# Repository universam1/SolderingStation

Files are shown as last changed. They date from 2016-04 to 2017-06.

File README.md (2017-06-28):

# SolderingStation

Schematics and Code for a DIY Weller RT soldering station.

Find original idea at https://debugginglab.wordpress.com/2014/10/30/soldering-station/

## Additions

- Calculating Power usage by measuring the input voltage
- Limit Power dynamically, displaying it
- allowing different voltage PSUs
- more UI changes
- more convenient Poti mappings
- introducing serial command to configure (more to do)

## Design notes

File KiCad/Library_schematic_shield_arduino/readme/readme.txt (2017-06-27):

# About:
library shield_arduino 

(for arduino board version make from 2009 and after)

#Contains: 
the KiCAD schematic for some "ARDUINO" board:

ARDUINO_as_UNO		schématic for build a shield or clone an "arduino as UNO " based on revision 3
ARDUINO_FIO		schématic for build a shield or clone an "arduino FIO" based on version 22
ARDUINO_MEGA		schématic for build a shield or clone an "arduino MEGA 2560 " based on revision 3 
ARDUINO_MICRO		schématic for build a shield or clone an "arduino MICRO " based on revision 3
ARDUINO_MINI_PRO	schématic for build a shield or clone an "arduino PRO MINI " based on version 10
ARDUINO_MINI		schématic for build a shield or clone an "arduino MINI " based on version 5
ARDUINO_NANO		schématic for build a shield or clone an "arduino NANO" based on version 2

/!\Attention/!\ 

GND/1, GND/2 ou TX/1, TX/2 ou 5V/1, 5V/2 ect... as the same in your board but it was separate in these modules.
Just for more free during your construction.

Schematics not contains the ISP connector.

Pin are placing like your official boards

Just verifi if pins are present, depending your board version and adjust in consequence.

Be careful the library may contain errors.

(partie en français)

/!\Attention/!\ 

Les pins marquées GND/1, GND/2 ou TX/1, TX/2 ou 5V/1, 5V/2 ect... sont connectées 
entre elles sur les cartes officielles. 
Sur les schémats je l'ai est dissocié pour vous laissez plus de 
liberté dans la fabriction de vos shields ou vos clones...

Les schémas ne contiennent pas le connecteur ISP.

L'arrangement des connections sur le schémat et suivant le placement des pins sur
les cartes officielles 

Vérifier la version de votre carte et la présence des pins. 
Ajuster en conséquence.

La librairie peut contenir des défauts alors vérifier deux fois.

Author: Jonathan Iapicco / France / 27 nov. 2014
License: GNU-GPL

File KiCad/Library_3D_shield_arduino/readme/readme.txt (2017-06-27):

# About
library 3D shield_arduino 

(for arduino board version make from 2009 and after)

#Contains: 
the KiCAD 3D views, formats: ".Wrl" and ".wings" for some
"ARDUINO" board:

arduino_MICRO_header.wings
arduino_MICRO_header.wrl
arduino_MICRO_header_down.wings
arduino_MICRO_header_down.wrl
arduino_MICRO_header_long.wings
arduino_MICRO_header_long.wrl
arduino_MICRO_pin_strip.wings
arduino_MICRO_pin_strip.wrl
arduino_MICRO_pin_strip_double.wings
arduino_MICRO_pin_strip_double.wrl
arduino_MICRO_pin_strip_down.wings
arduino_MICRO_pin_strip_down.wrl

arduino_MINI_header.wings
arduino_MINI_header.wrl
arduino_MINI_header_down.wings
arduino_MINI_header_down.wrl
arduino_MINI_header_long.wings
arduino_MINI_header_long.wrl
arduino_MINI_pin_strip.wings
arduino_MINI_pin_strip.wrl
arduino_MINI_pin_strip_double.wings
arduino_MINI_pin_strip_double.wrl
arduino_MINI_pin_strip_down.wings
arduino_MINI_pin_strip_down.wrl

arduino_FIO_header.wings
arduino_FIO_header.wrl
arduino_FIO_header_down.wings
arduino_FIO_header_down.wrl
arduino_FIO_header_long.wings
arduino_FIO_header_long.wrl
arduino_FIO_pin_strip.wings
arduino_FIO_pin_strip.wrl
arduino_FIO_pin_strip_double.wings
arduino_FIO_pin_strip_double.wrl
arduino_FIO_pin_strip_down.wings
arduino_FIO_pin_strip_down.wrl

arduino_MEGA_header.wings
arduino_MEGA_header.wrl
arduino_MEGA_header_down.wings
arduino_MEGA_header_down.wrl
arduino_MEGA_header_down+.wings
arduino_MEGA_header_down+.wrl
arduino_MEGA_header_long.wings
arduino_MEGA_header_long.wrl
arduino_MEGA_header_long+.wings
arduino_MEGA_header_long+.wrl
arduino_MEGA_pin_strip.wings
arduino_MEGA_pin_strip.wrl
arduino_MEGA_pin_strip+.wings
arduino_MEGA_pin_strip+.wrl
arduino_MEGA_pin_strip_double.wings
arduino_MEGA_pin_strip_double.wrl
arduino_MEGA_pin_strip_down.wings
arduino_MEGA_pin_strip_down.wrl

arduino_MINI_PRO_header.wings
arduino_MINI_PRO_header.wrl
arduino_MINI_PRO_header_down.wings
arduino_MINI_PRO_header_down.wrl
arduino_MINI_PRO_header_long.wings
arduino_MINI_PRO_header_long.wrl
arduino_MINI_PRO_pin_strip.wings
arduino_MINI_PRO_pin_strip.wrl
arduino_MINI_PRO_pin_strip_double.wings
arduino_MINI_PRO_pin_strip_double.wrl
arduino_MINI_PRO_pin_strip_down.wings
arduino_MINI_PRO_pin_strip_down.wrl

arduino_NANO_header.wings
arduino_NANO_header.wrl
arduino_NANO_header_down.wings
arduino_NANO_header_down.wrl
arduino_NANO_header_long.wings
arduino_NANO_header_long.wrl
arduino_NANO_pin_strip.wings
arduino_NANO_pin_strip.wrl
arduino_NANO_pin_strip_double.wings
arduino_NANO_pin_strip_double.wrl
arduino_NANO_pin_strip_down.wings
arduino_NANO_pin_strip_down.wrl

arduino_UNO_header.wings
arduino_UNO_header.wrl
arduino_UNO_header_down.wings
arduino_UNO_header_down.wrl
arduino_UNO_header_long.wings
arduino_UNO_header_long.wrl
arduino_UNO_pin_strip.wings
arduino_UNO_pin_strip.wrl
arduino_UNO_pin_strip_double.wings
arduino_UNO_pin_strip_double.wrl
arduino_UNO_pin_strip_down.wings
arduino_UNO_pin_strip_down.wrl

All view are made in "inch" with any export offset.

The directory "demo_library_wings" contains all modules 
3D for demonstration, you can use it for select your 3D view.

File "extra.wings" contain all pins i used and little more in format ".wings".
You can use for create your personnal view.
 
For open you need the software -> "wings 3D" 
You can download at : http://www.wings3d.com/

Be careful the library may contain errors

(partie en français)

Toutes les vues sont construites en "pouce" sans offset à l'exportation.

Le répertoire "demo_library_wings" contient tous l'ensemble des modules 3D.
Vous pouvez vous en servir pour visualiser et choisir votre vue 3D.

Le fichier "extra.wings" contient les éléments 3D au format ".wings" que j'ai utilisé pour
faire les modules. Vous pouvez ainsi adapter vos vues selon vos besoins.

Pour utiliser les fichier ".wings" il vous faut le logiciel "wings 3D"
que vous pouvez trouver ici: http://www.wings3d.com/

Attention les vues peuvent contenir des défauts alors vérifier deux fois.

Author: Jonathan Iapicco / France / 27 nov. 2014
License: GNU-GPL

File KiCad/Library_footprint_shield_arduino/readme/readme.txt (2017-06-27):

# About:
library footprint SHIELD_ARDUINO 

(for arduino board version make from 2009 and after)

#Contains: 
the KiCAD footprint for some "ARDUINO" board:

ARDUINO_FIO_V22				Footprint contain only pin connectors. 
ARDUINO_FIO_V22_CONTOUR			Footprint contain pin connectors, board contour and position (VCC, USB, ISP, RESET button).
ARDUINO_FIO_V22_ELL			Footprint with large pads.
ARDUINO_FIO_V22_CONTOUR-ELL		Footprint with large pads.
ARDUINO_MEGA_2560_R3			Footprint contain only pin connectors and holes.
ARDUINO_MEGA_2560_R3_CONTOUR 		Footprint contain pin connectors, board contour and position (VCC, USB, ISP, RESET button).
ARDUINO_MEGA_2560_R3_ELL		Footprint with large pads.
ARDUINO_MEGA_2560_R3_CONTOUR_ELL	Footprint with large pads.
ARDUINO_MICRO_R3			Footprint contain only pin connectors and holes.
ARDUINO_MICRO_R3_CONTOUR		Footprint contain pin connectors, board contour and position (USB, ISP, RESET button).
ARDUINO_MICRO_R3_ELL			Footprint with large pads.
ARDUINO_MICRO_R3_CONTOUR_ELL		Footprint with large pads.
ARDUINO_MINI_PRO_V10			Footprint contain only pin connectors.
ARDUINO_MINI_PRO_V10_CONTOUR		Footprint contain pin connectors, board contour and position (RESET button).
ARDUINO_MINI_PRO_V10_ELL		Footprint with large pads.
ARDUINO_MINI_PRO_V10_CONTOUR_ELL	Footprint with large pads.
ARDUINO_MINI_V5				Footprint contain only pin connectors.
ARDUINO_MINI_V5_CONTOUR			Footprint contain pin connectors, board contour and position (RESET button).	
ARDUINO_MINI_V5_ELL			Footprint with large pads.	
ARDUINO_MINI_V5_CONTOUR_ELL		Footprint with large pads.
ARDUINO_NANO_2				Footprint contain only pin connectors and holes.
ARDUINO_NANO_2_CONTOUR			Footprint contain pin connectors, board contour and position (USB, ISP, RESET button).
ARDUINO_NANO_2_ELL			Footprint with large pads.	
ARDUINO_NANO_2_CONTOUR_ELL		Footprint with large pads.
ARDUINO_as_UNO_R3			Footprint contain only pin connectors and holes.
ARDUINO_as_UNO_R3_CONTOUR		Footprint contain pin connectors, board contour and position (VCC, USB, ISP, RESET button).
ARDUINO_as_UNO_R3_ELL			Footprint with large pads.
ARDUINO_as_UNO_R3_CONTOUR_ELL		Footprint with large pads.

/!\IMPORTANT: use directory "SHIELD_ARDUINO.pretty" if your have a new KICAD version (version >= BZR 5000).
Else if your have an old KICAD version use "SHIELD_ARDUINO.mod" /!\ 

GND/1, GND/2 ou TX/1, TX/2 ou 5V/1, 5V/2 ect... as the same in your board but it was separate in these modules.
Just for more free during your construction.

The postion of connectors (VCC, USB, ISP and reset) and holes are there for information purposes.
Adujst your footprint what do you want. 

Be careful the library may contain errors.

(Partie en français)

/!\Attention/!\ 

Les pins marquées GND/1, GND/2 ou TX/1, TX/2 ou 5V/1, 5V/2 ect... sont connectées 
entre elles sur les cartes officielles mais séparées sur ces modules. Cela vous laisse plus de liberté. 

Utiliser le répertoire "SHIELD_ARDUINO.pretty" si votre version de kicad est supérieur ou égale à la
"BZR 5110".
Sinon utiliser "SHIELD_ARDUINO.mod".

Les empreintes type "arduino_board_contour" contiennent le contour des cartes.
Mais aussi l'emplacement des trous, du connecteur "ISP", du bouton "RESET", des connecteurs 
"USB" et de l'alimentation si il y en a. 
Ils sont tracés avec des traits d'une épaisseur de "0.01mm" alors que les contours sont en "0.15mm".

Le but étant de vous donnez un maximum d'informations et d'ajuster selon vos besoins. 

Vérifier la version de votre carte et la présence des pins. 
Ajuster en conséquence.

La librairie peut contenir des erreurs alors vérifier deux fois.

Author:	 Jonathan Iapicco / France / 27 nov. 2014
License: GNU-GPL

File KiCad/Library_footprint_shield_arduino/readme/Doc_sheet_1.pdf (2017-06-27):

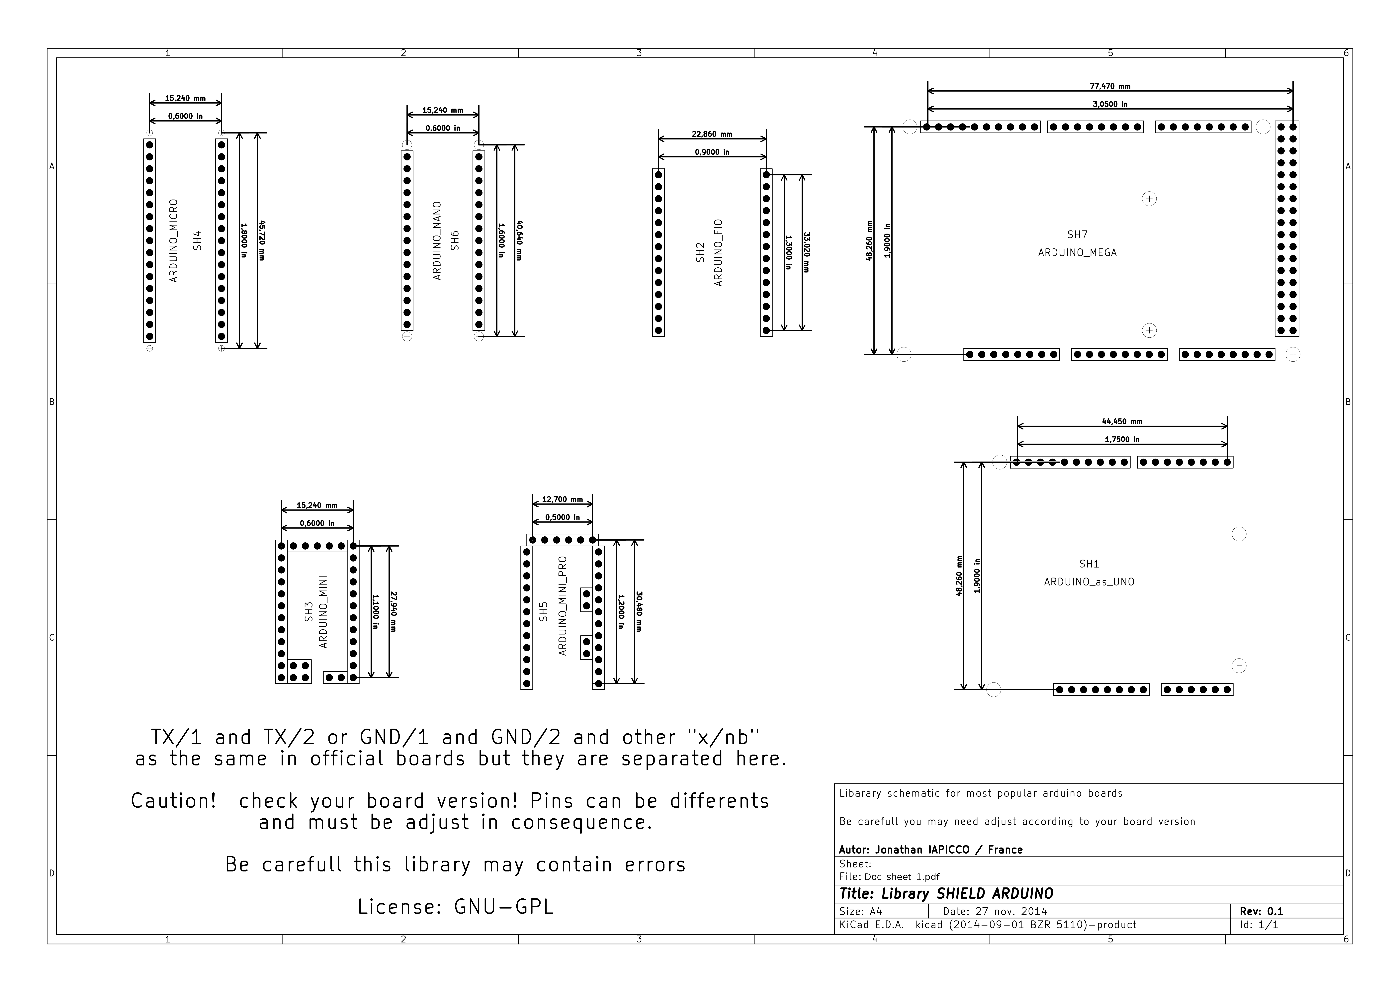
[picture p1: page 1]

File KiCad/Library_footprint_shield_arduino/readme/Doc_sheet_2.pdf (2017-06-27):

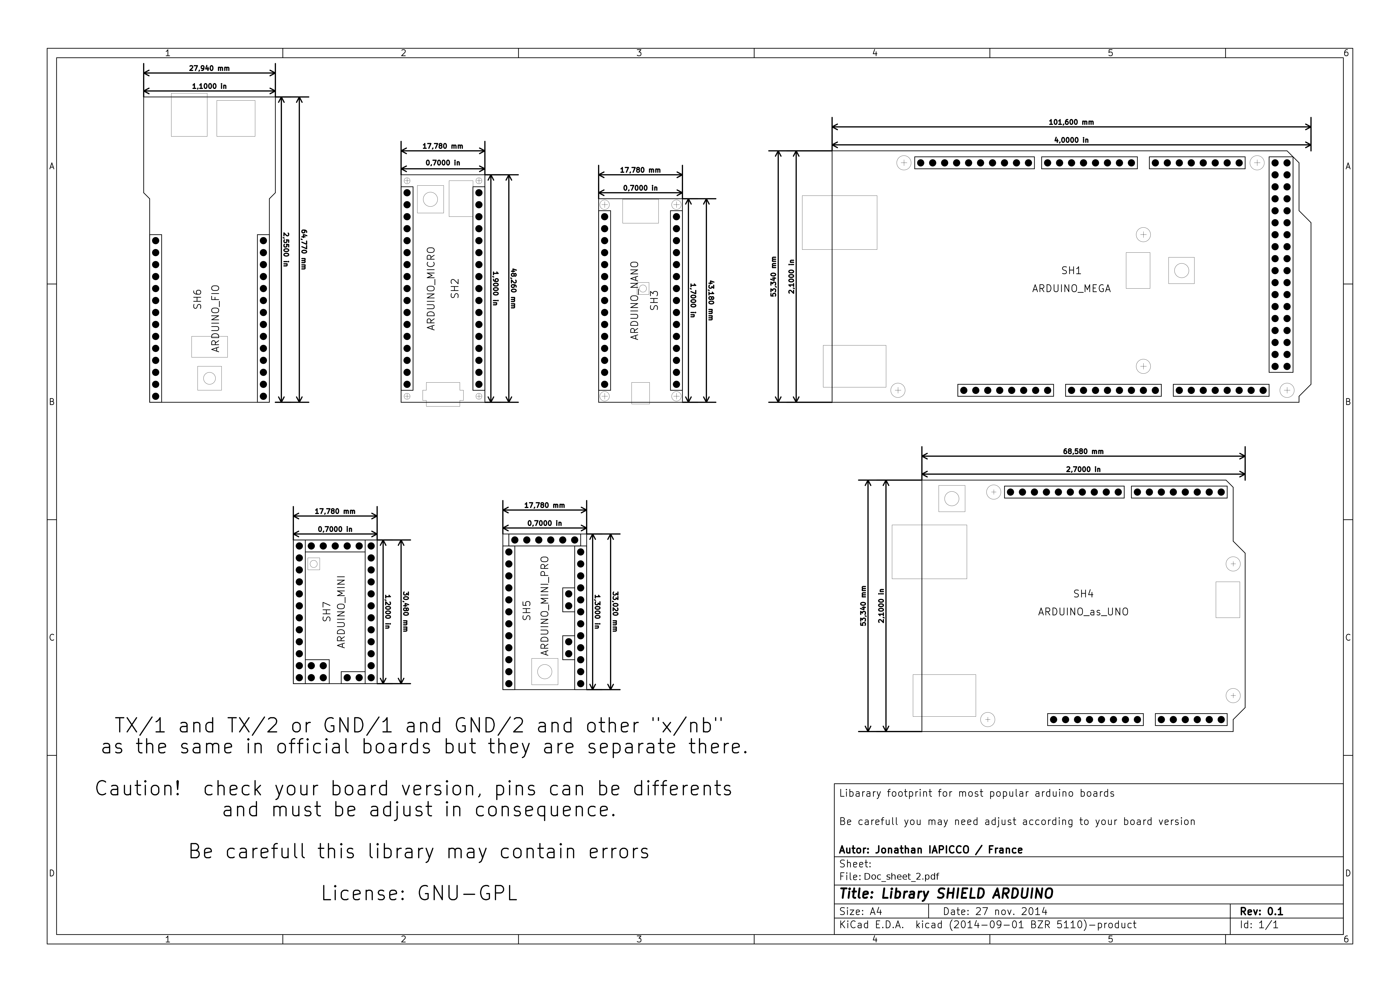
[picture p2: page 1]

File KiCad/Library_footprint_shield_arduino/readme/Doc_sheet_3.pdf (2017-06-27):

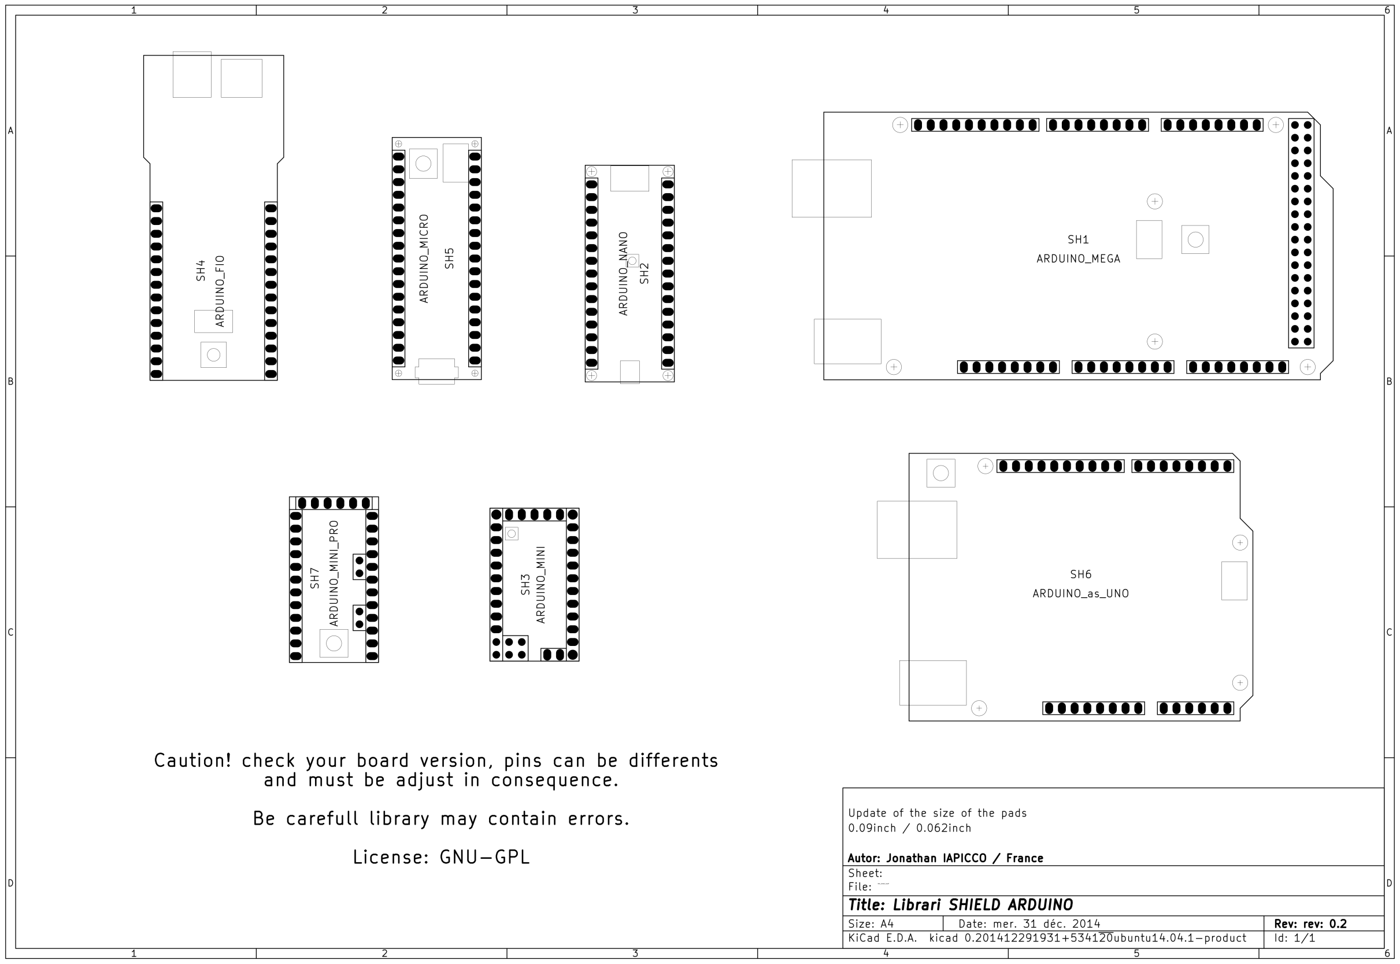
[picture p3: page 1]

Doc_sheet_3.pdf

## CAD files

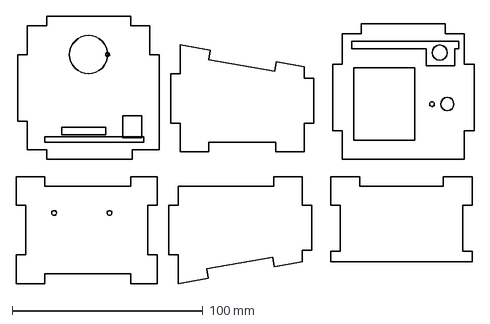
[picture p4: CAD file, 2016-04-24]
2D5/solderstation_gehäuse.dxf
240.0 x 140.1 mm

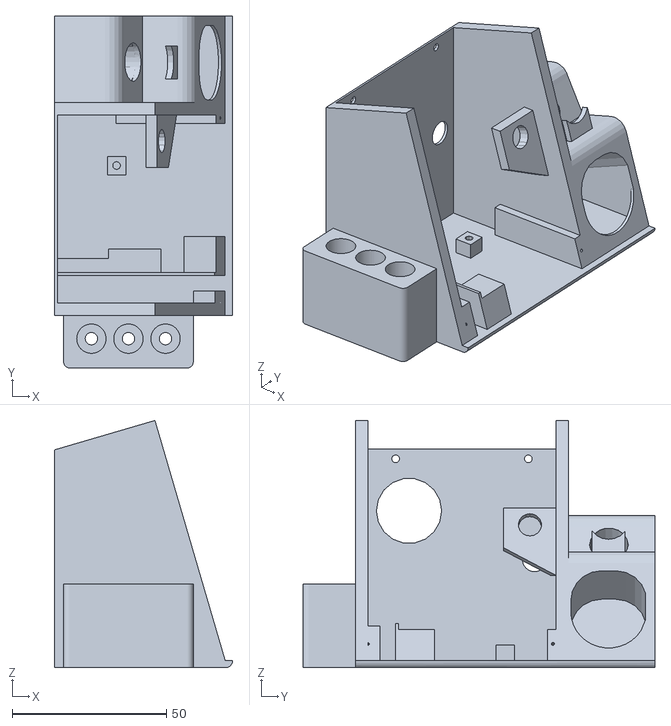
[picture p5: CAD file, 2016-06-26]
3D/lotstationv2.2.stl
57.7 x 114.0 x 80.0

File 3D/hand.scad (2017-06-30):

use<thread.scad>;

$fn = 50;

$hl = 100;
$h1 = 10.6;
$h2 = 28.6;
$h3 = 14;
$h4 = 12;
$h5 = $hl - ($h1 + $h2 + $h3 + $h4);

module huelle()
{
    difference()
    {
        translate([ 0, 0, 41 ])
            scale([ 0.18, 0.18, 1 ])
            sphere(r = 62);
        translate([ 0, 0, -50 ]) cube(size = [ 100, 100, 100 ], center = true);
        translate([ 0, 0, $hl + 50 ]) cube(size = [ 100, 100, 100 ], center = true);
    }
}

module handle_bottom()
{
    difference()
    {
        union()
        {
            huelle();

            // cylinder(h=$h1+$h2+$h3, r=13/2);
        }
        cylinder(h = $h1, r = 9.8 / 2);
        translate([ 0, 0, $h1 ]) cylinder(h = $h2, r = 10.6 / 2);
        translate([ 0, 0, $h1 + $h2 ]) metric_thread(diameter = 15, pitch = 1.5, length = $h3, internal = true);
        translate([ 0, 0, $h1 + $h2 + $h3 + 50 ]) cube(size = [ 100, 100, 100 ], center = true);
    }
}

module handle_top()
{
    difference()
    {
    union()
    {
        difference()
        {
            huelle();
            translate([ 0, 0, $h1 + $h2 + $h3 - 50 ]) cube(size = [ 100, 100, 100 ], center = true);
        }
        difference()
        {
            translate([ 0, 0, $h1 + $h2 + 2 ]) metric_thread(diameter = 14.4, pitch = 1.5, length = $h3 - 2);
            translate([ 0, 0, $h1 + $h2 ]) cylinder(h = $h3, r = 6.1 / 2);
        }
    }
        // union()
        // {
            // translate([ 0, 0, $h1 + $h2 + $h3 ]) cylinder(h = $h4, r = 12.8 / 2);
            // translate([ 0, 0, $h1 + $h2 + $h3 + $h4 ]) cylinder(h = $h5, r = 12.8 / 2, r2 = 8 / 2);
        
        translate([ 0, 0, $h1 + $h2 + $h3 ]) cylinder(h = $h4 + $h5, r = 4.8 / 2);
    }
}

difference()
{
    union()
    {
        // handle_top();
        handle_bottom();
    }
    // translate([ 0, -15, 0 ]) cube([ 20, 30, 200 ]);
}

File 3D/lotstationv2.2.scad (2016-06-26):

$fn=50;

module object() {
    translate([28.5,32.20,0.25]) {
        import("/Users/waldemar/Projekte/SolderingStation/3D/lotstationv2.1.stl");
    }
    translate([0,52, 13]) color("red") cube([1,12,14]);
}

module holder() {
    union() {
        translate([12,-7.5,14.5]) cylinder(h= 13, r=9.5/2);
        translate([12,-7.5,0]) cylinder(h= 30, r=4/2);
    }
}

difference() {
    object();
    translate([-5,58, 35]) rotate([0,90,0]) cylinder(h= 30, r=7.9/2);
}

difference() {
    translate([5,-15,0]) minkowski() {
        cube([39,16.5,26]);
        cylinder(r=2,h=1);
    }
     
    holder();
    translate([12.5, 0,0]) holder();
    translate([25, 0,0]) holder();
}

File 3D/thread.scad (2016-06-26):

/*
 * ISO-standard metric threads, following this specification:
 *          http://en.wikipedia.org/wiki/ISO_metric_screw_thread
 *
 * Dan Kirshner - dan_kirshner@yahoo.com
 *
 * You are welcome to make free use of this software.  Retention of my
 * authorship credit would be appreciated.
 *
 * Version 1.8.  2016-01-08  Option: (non-standard) angle.
 * Version 1.7.  2015-11-28  Larger x-increment - for small-diameters.
 * Version 1.6.  2015-09-01  Options: square threads, rectangular threads.
 * Version 1.5.  2015-06-12  Options: thread_size, groove.
 * Version 1.4.  2014-10-17  Use "faces" instead of "triangles" for polyhedron
 * Version 1.3.  2013-12-01  Correct loop over turns -- don't have early cut-off
 * Version 1.2.  2012-09-09  Use discrete polyhedra rather than linear_extrude ()
 * Version 1.1.  2012-09-07  Corrected to right-hand threads!
 */

// Examples.
//
// Standard M8 x 1.
// metric_thread (diameter=8, pitch=1, length=4);

// Square thread.
// metric_thread (diameter=8, pitch=1, length=4, square=true);

// Non-standard: long pitch, same thread size.
//metric_thread (diameter=8, pitch=4, length=4, thread_size=1, groove=true);

// Non-standard: 20 mm diameter, long pitch, square "trough" width 3 mm,
// depth 1 mm.
//metric_thread (diameter=20, pitch=8, length=16, square=true, thread_size=6, 
//               groove=true, rectangle=0.333);

// English: 1/4 x 20.
//english_thread (diameter=1/4, threads_per_inch=20, length=1);

// Thread for mounting on Rohloff hub.
//difference () {
//   cylinder (r=20, h=10, $fn=100);
//
//   metric_thread (diameter=34, pitch=1, length=10, internal=true, n_starts=6);
//}


// ----------------------------------------------------------------------------
function segments (diameter) = min (50, ceil (diameter*6));


// ----------------------------------------------------------------------------
// internal -    true = clearances for internal thread (e.g., a nut).
//               false = clearances for external thread (e.g., a bolt).
//               (Internal threads should be "cut out" from a solid using
//               difference ()).
// n_starts -    Number of thread starts (e.g., DNA, a "double helix," has
//               n_starts=2).  See wikipedia Screw_thread.
// thread_size - (non-standard) size of a single thread "V" - independent of
//               pitch.  Default: same as pitch.
// groove      - (non-standard) subtract inverted "V" from cylinder (rather than
//               add protruding "V" to cylinder).
// square      - Square threads (per 
//               https://en.wikipedia.org/wiki/Square_thread_form).
// rectangle   - (non-standard) "Rectangular" thread - ratio depth/width
//               Default: 1 (square).
// angle       - (non-standard) angle (deg) of thread side from perpendicular to
//               axis (default = standard = 30 degrees).
module metric_thread (diameter=8, pitch=1, length=1, internal=false, n_starts=1,
                      thread_size=-1, groove=false, square=false, rectangle=0,
                      angle=30)
{
   // thread_size: size of thread "V" different than travel per turn (pitch).
   // Default: same as pitch.
   local_thread_size = thread_size == -1 ? pitch : thread_size;
   local_rectangle = rectangle ? rectangle : 1;

   n_segments = segments (diameter);
   h = (square || rectangle) ? local_thread_size*local_rectangle/2 : local_thread_size * cos (angle);

   h_fac1 = (square || rectangle) ? 0.90 : 0.625;

   // External thread includes additional relief.
   h_fac2 = (square || rectangle) ? 0.95 : 5.3/8;

   if (! groove) {
      metric_thread_turns (diameter, pitch, length, internal, n_starts, 
                           local_thread_size, groove, square, rectangle, angle);
   }

   difference () {

      // Solid center, including Dmin truncation.
      if (groove) {
         cylinder (r=diameter/2, h=length, $fn=n_segments);
      } else if (internal) {
         cylinder (r=diameter/2 - h*h_fac1, h=length, $fn=n_segments);
      } else {

         // External thread.
         cylinder (r=diameter/2 - h*h_fac2, h=length, $fn=n_segments);
      }

      if (groove) {
         metric_thread_turns (diameter, pitch, length, internal, n_starts, 
                              local_thread_size, groove, square, rectangle,
                              angle);
      }
   }
}


// ----------------------------------------------------------------------------
// Input units in inches.
// Note: units of measure in drawing are mm!
module english_thread (diameter=0.25, threads_per_inch=20, length=1,
                      internal=false, n_starts=1, thread_size=-1, groove=false,
                      square=false, rectangle=0)
{
   // Convert to mm.
   mm_diameter = diameter*25.4;
   mm_pitch = (1.0/threads_per_inch)*25.4;
   mm_length = length*25.4;

   echo (str ("mm_diameter: ", mm_diameter));
   echo (str ("mm_pitch: ", mm_pitch));
   echo (str ("mm_length: ", mm_length));
   metric_thread (mm_diameter, mm_pitch, mm_length, internal, n_starts, 
                  thread_size, groove, square, rectangle);
}

// ----------------------------------------------------------------------------
module metric_thread_turns (diameter, pitch, length, internal, n_starts, 
                            thread_size, groove, square, rectangle, angle)
{
   // Number of turns needed.
   n_turns = floor (length/pitch);

   intersection () {

      // Start one below z = 0.  Gives an extra turn at each end.
      for (i=[-1*n_starts : n_turns+1]) {
         translate ([0, 0, i*pitch]) {
            metric_thread_turn (diameter, pitch, internal, n_starts, 
                                thread_size, groove, square, rectangle, angle);
         }
      }

      // Cut to length.
      translate ([0, 0, length/2]) {
         cube ([diameter*3, diameter*3, length], center=true);
      }
   }
}


// ----------------------------------------------------------------------------
module metric_thread_turn (diameter, pitch, internal, n_starts, thread_size,
                           groove, square, rectangle, angle)
{
   n_segments = segments (diameter);
   fraction_circle = 1.0/n_segments;
   for (i=[0 : n_segments-1]) {
      rotate ([0, 0, i*360*fraction_circle]) {
         translate ([0, 0, i*n_starts*pitch*fraction_circle]) {
            thread_polyhedron (diameter/2, pitch, internal, n_starts, 
                               thread_size, groove, square, rectangle, angle);
         }
      }
   }
}


// ----------------------------------------------------------------------------
// z (see diagram) as function of current radius.
// (Only good for first half-pitch.)
function z_fct (current_radius, radius, pitch, angle)
   = 0.5* (current_radius - (radius - 0.875*pitch*cos (angle)))
                                                       /cos (angle);

// ----------------------------------------------------------------------------
module thread_polyhedron (radius, pitch, internal, n_starts, thread_size,
                          groove, square, rectangle, angle)
{
   n_segments = segments (radius*2);
   fraction_circle = 1.0/n_segments;

   local_rectangle = rectangle ? rectangle : 1;

   h = (square || rectangle) ? thread_size*local_rectangle/2 : thread_size * cos (angle);
   outer_r = radius + (internal ? h/20 : 0); // Adds internal relief.
   //echo (str ("outer_r: ", outer_r));

   // A little extra on square thread -- make sure overlaps cylinder.
   h_fac1 = (square || rectangle) ? 1.1 : 0.875;
   inner_r = radius - h*h_fac1; // Does NOT do Dmin_truncation - do later with
                                // cylinder.

   translate_y = groove ? outer_r + inner_r : 0;
   reflect_x   = groove ? 1 : 0;

   // Make these just slightly bigger (keep in proportion) so polyhedra will
   // overlap.
   x_incr_outer = (! groove ? outer_r : inner_r) * fraction_circle * 2 * PI * 1.02;
   x_incr_inner = (! groove ? inner_r : outer_r) * fraction_circle * 2 * PI * 1.02;
   z_incr = n_starts * pitch * fraction_circle * 1.005;

   /*
    (angles x0 and x3 inner are actually 60 deg)

                          /\  (x2_inner, z2_inner) [2]
                         /  \
   (x3_inner, z3_inner) /    \
                  [3]   \     \
                        |\     \ (x2_outer, z2_outer) [6]
                        | \    /
                        |  \  /|
             z          |[7]\/ / (x1_outer, z1_outer) [5]
             |          |   | /
             |   x      |   |/
             |  /       |   / (x0_outer, z0_outer) [4]
             | /        |  /     (behind: (x1_inner, z1_inner) [1]
             |/         | /
    y________|          |/
   (r)                  / (x0_inner, z0_inner) [0]

   */

   x1_outer = outer_r * fraction_circle * 2 * PI;

   z0_outer = z_fct (outer_r, radius, thread_size, angle);
   //echo (str ("z0_outer: ", z0_outer));
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

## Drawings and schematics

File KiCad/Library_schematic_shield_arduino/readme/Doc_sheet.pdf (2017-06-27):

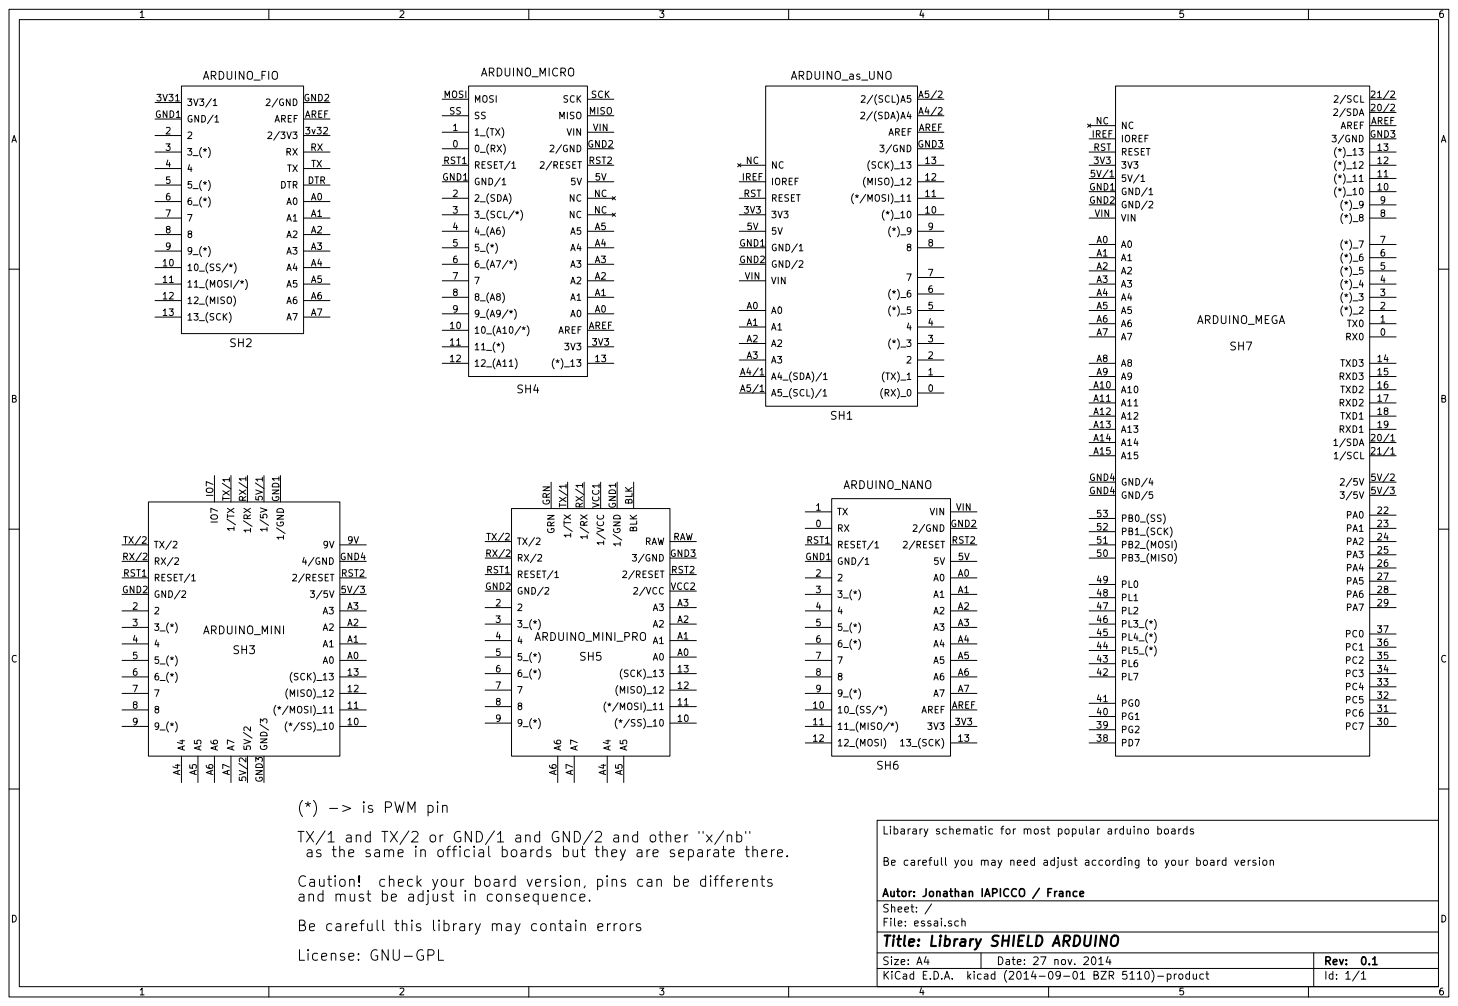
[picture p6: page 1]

(*) -> is PWM pin
TX/1 and TX/2 or GND/1 and GND/2 and other "x/nb"
as the same in official boards but they are separate there.
Caution! check your board version, pins can be differents
and must be adjust in consequence.
Be carefull this library may contain errors
License: GNU-GPL

Libarary schematic for most popular arduino boards

File: essai.sch Sheet: / Autor: Jonathan IAPICCO / France Be carefull you may need adjust according to your board version

Id: 1/1 Title: Library SHIELD ARDUINO

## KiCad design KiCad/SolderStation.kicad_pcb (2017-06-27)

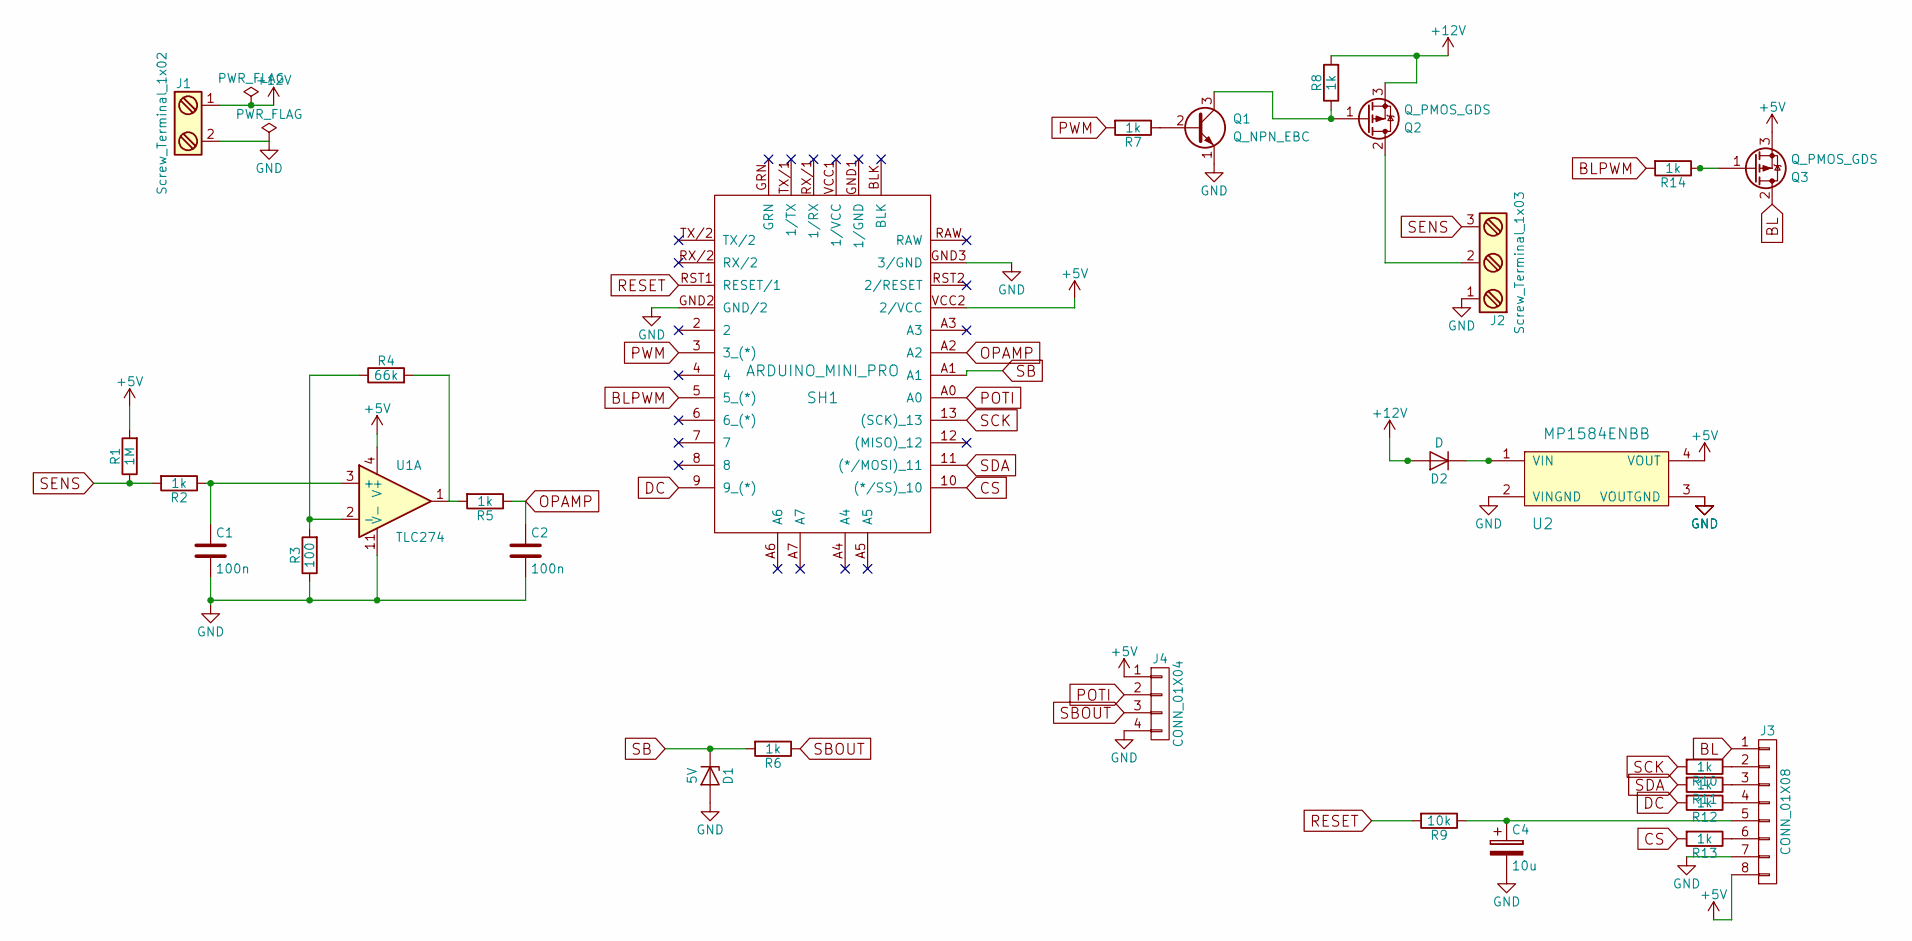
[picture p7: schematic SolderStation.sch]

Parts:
C1, C2: 100n; C_Disc_D5.0mm_W2.5mm_P2.50mm
C4: 10u; CP_Radial_D7.5mm_P2.50mm
D1: 5V; D_DO-15_P5.08mm_Vertical_AnodeUp
D2: D; D_DO-15_P5.08mm_Vertical_AnodeUp
J1: Screw_Terminal_1x02; bornier2
J2: Screw_Terminal_1x03; bornier3
J3: CONN_01X08; Pin_Header_Straight_1x08_Pitch2.54mm
J4: CONN_01X04; Pin_Header_Straight_1x04_Pitch2.54mm
Q1: Q_NPN_EBC; TO-92_Molded_Wide
Q2: Q_PMOS_GDS; TO-220_Vertical
Q3: Q_PMOS_GDS; SOT-23_Handsoldering
R1: 1M; R_Axial_DIN0207_L6.3mm_D2.5mm_P7.62mm_Horizontal
R2, R5, R6, R7, R8, R10, R11, R12, R13, R14: 1k; R_Axial_DIN0207_L6.3mm_D2.5mm_P7.62mm_Horizontal
R3: 100; R_Axial_DIN0207_L6.3mm_D2.5mm_P7.62mm_Horizontal
R4: 66k; R_Axial_DIN0207_L6.3mm_D2.5mm_P7.62mm_Horizontal
R9: 10k; R_Axial_DIN0207_L6.3mm_D2.5mm_P7.62mm_Horizontal
SH1: ARDUINO_MINI_PRO; ARDUINO_MINI_PRO_V10
U1: TLC274; DIP-14_W7.62mm_Socket_LongPads
U2: MP1584ENBB; MP1584_buck_module

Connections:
+5V: J3.8, J4.1, Q3.3 (S), R1.2, SH1.VCC2 (2/VCC), U1.4 (V+), U2.4 (VOUT)
+12V: D2.2 (A), J1.1, Q2.3 (S), R8.2
BL: J3.1, Q3.2 (D)
BLPWM: R14.2, SH1.5 (5_(*))
CS: R13.2, SH1.10 ((*/SS)_10)
DC: R12.2, SH1.9 (9_(*))
GND: C1.2, C2.2, C4.2, D1.2 (A), J1.2, J2.1, J3.7, J4.4, Q1.1 (E), R3.1, SH1.GND2 (GND/2), SH1.GND3 (3/GND), U1.11 (V-), U2.2 (VINGND), U2.3 (VOUTGND)
unnamed: C1.1, R2.1, U1.3 (+)
unnamed: C4.1, J3.5, R9.1
unnamed: D2.1 (K), U2.1 (VIN)
unnamed: J2.2, Q2.2 (D)
unnamed: J3.2, R10.1
unnamed: J3.3, R11.1
unnamed: J3.4, R12.1
unnamed: J3.6, R13.1
unnamed: Q1.2 (B), R7.1
unnamed: Q1.3 (C), Q2.1 (G), R8.1
unnamed: Q3.1 (G), R14.1
unnamed: R3.2, R4.1, U1.2 (-)
unnamed: R4.2, R5.2, U1.1
OPAMP: C2.1, R5.1, SH1.A2
POTI: J4.2, SH1.A0
PWM: R7.2, SH1.3 (3_(*))
RESET: R9.2, SH1.RST1 (RESET/1)
SB: D1.1 (K), R6.2, SH1.A1
SBOUT: J4.3, R6.1
SCK: R10.2, SH1.13 ((SCK)_13)
SDA: R11.2, SH1.11 ((*/MOSI)_11)
SENS: J2.3, R1.1, R2.2

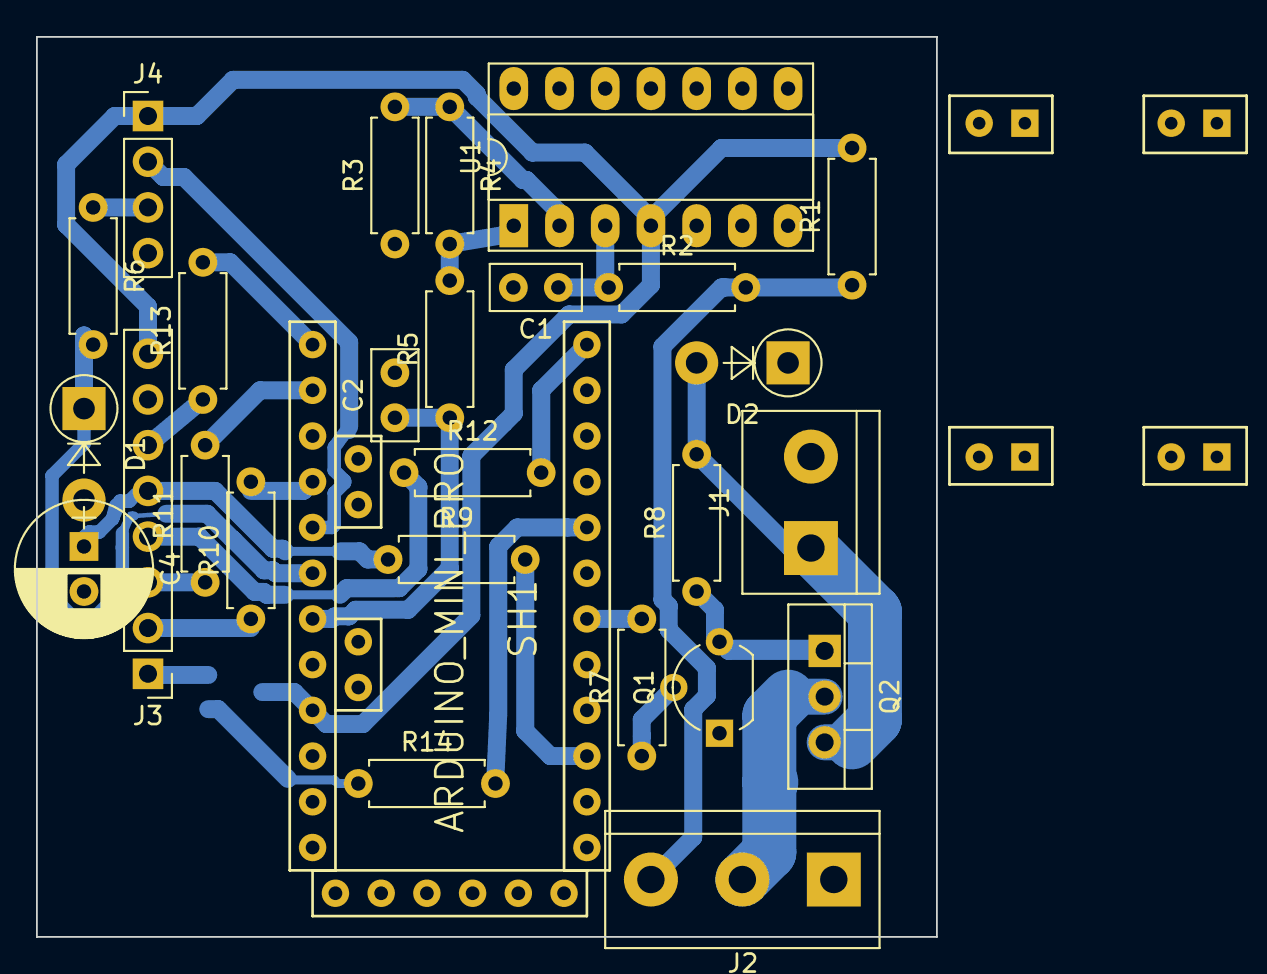
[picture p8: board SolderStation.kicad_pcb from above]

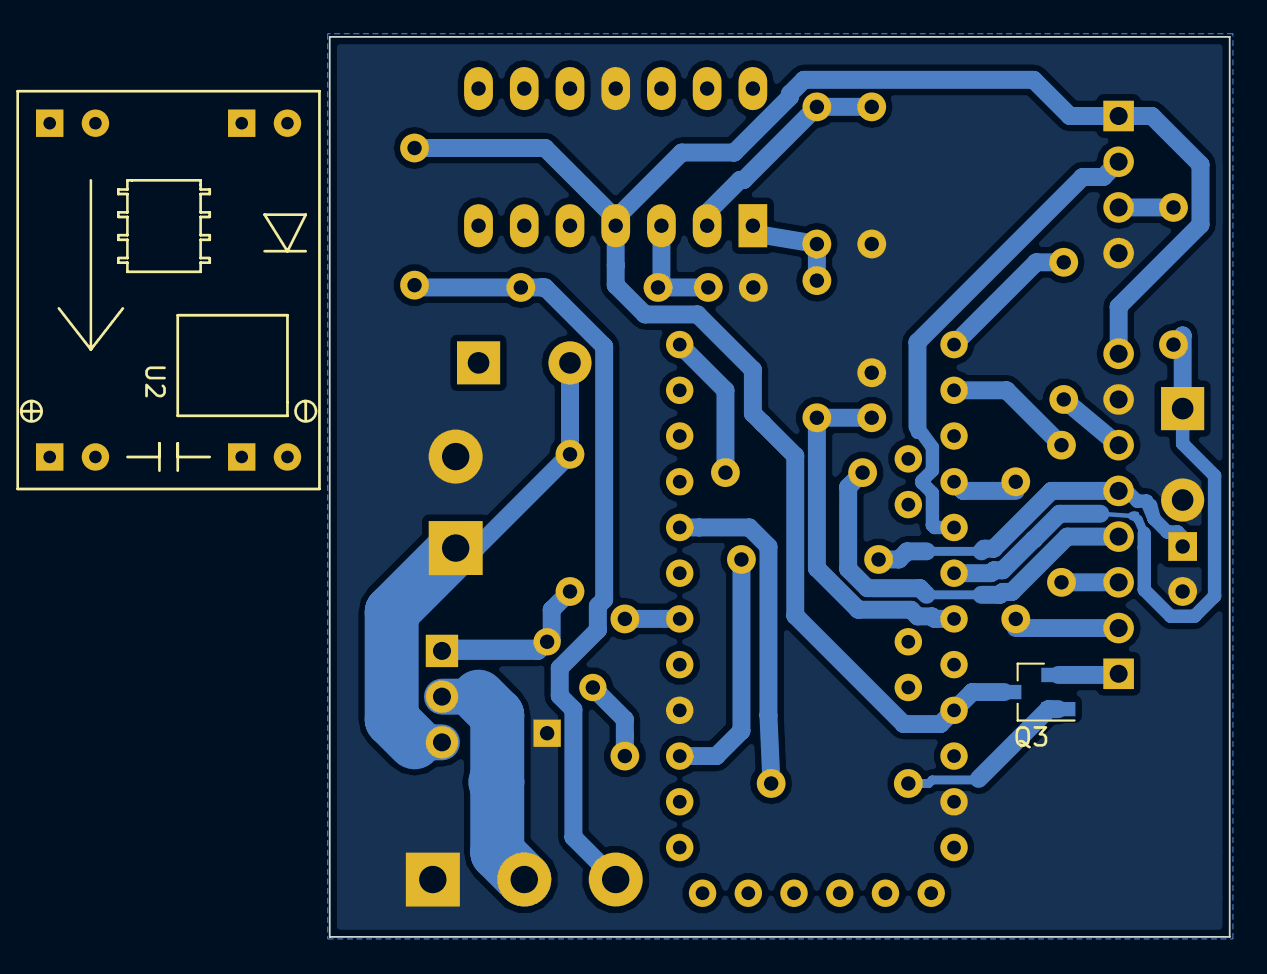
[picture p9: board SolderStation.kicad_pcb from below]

Board: 2 copper layers, 50.0 x 50.0 mm, 29 parts (2 on the bottom side), 29 nets.

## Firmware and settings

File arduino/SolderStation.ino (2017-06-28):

//*******************************//
// Soldering Station
// Matthias Wagner
// www.k-pank.de/so
// Get.A.Soldering.Station@gmail.com
//*******************************//

#define __PROG_TYPES_COMPAT__
// #include <FastLED.h>
#include <Adafruit_GFX.h>	// Core graphics library
#include <Adafruit_ST7735.h> // Hardware-specific library
#include <SPI.h>

#include <SerialCommand.h>
#include "iron.h"
#include "stationLOGO.h"

#define VERSION "1.7" //Version der Steuerung
// #define INTRO

// #define LED_PIN 6
#define BRIGHTNESS 255
#define MAXWATT 40
#define INTVUPD 123

//Missing color in TFT lib
#define ST7735_GREY 0x632C

#define STANDBYin A1
#define POTI A0
#define TEMPin A2
#define PWMpin 3
#define BLpin 5
#define PINvolt A3
// #define BLpinold  5

#define CNTRL_GAIN 10
#define POTIOFF 10

#define DELAY_MAIN_LOOP 10
#define DELAY_MEASURE 10
// #define ADC_TO_TEMP_GAIN 0.53 //Mit original Weller Station verglichen
// #define ADC_TO_TEMP_OFFSET 25.0
#define ADC_TO_TEMP_GAIN 0.42
#define ADC_TO_TEMP_OFFSET 60.0
#define STANDBY_TEMP 90

#define OVER_SHOT 2
#define MAX_PWM_LOW 80
#define MAX_PWM_HI 255 //254
#define MAX_POTI 400   //400Grad C

#define JITTER 2				  // Hysterese um die Anzeige zu beruhigen
#define DISPLAY_REFRESH 500		  // Zeit um die Hysterese zu initialiseren
#define AUTO_OFF 600000			  // Zeit für das Ausschalten der Heizung (10min)
#define DISPLAY_FADE_DIFF_TEMP 20 // Temperaturabstand für den Übergang von rot nach grün = gelb
#define DISPLAY_FADE_DIFF 35	  // Temperaturband für das Aus/Einblenden von rot bzw. grün
								  // DISPLAY_FADE_DIFF muss kleiner sein als DISPLAY_FADE_DIFF_TEMP

#define PWM_DIV 1024 //default: 64   31250/64 = 2ms

// Define various ADC prescaler
const unsigned char PS_16 = (1 << ADPS2);
const unsigned char PS_32 = (1 << ADPS2) | (1 << ADPS0);
const unsigned char PS_64 = (1 << ADPS2) | (1 << ADPS1);
const unsigned char PS_128 = (1 << ADPS2) | (1 << ADPS1) | (1 << ADPS0);

#define RTresist 2.2
#define VOLTDIVIDER 34.0

//V1.5
#define dc 9
#define rst 12
#define cs_tft 10

Adafruit_ST7735 tft = Adafruit_ST7735(cs_tft, dc, rst); // Invoke custom library
SerialCommand sCmd;

int pwm = 0; //pwm Out Val 0.. 255
int soll_temp = 0;
int soll_temp_tmp = 0;
int disp_soll_temp = 0;
boolean standby_act = false;
boolean standby_act_old = false;
boolean autoOFF = false;
boolean autoOFF_old = false;
unsigned long refreshMillis = 0;
unsigned long autoOffMillis = 0;
unsigned long pwmMillis = 0;
// CRGB led[1];
float volt;
uint8_t watt;
uint32_t lastVupd;

uint8_t calcPower(float volt, uint16_t pwm, float resist = RTresist)
{
	float curr = volt / resist;
	curr = curr * volt / 255 * pwm;
	// Serial.print("V: ");
	// Serial.println(volt);
	// Serial.print("P: ");
	// Serial.println(curr);
	return curr;
}

float getVolt()
{
	return analogRead(PINvolt) / VOLTDIVIDER;
}

void setPower()
{
	char *arg;
	uint8_t power;
	arg = sCmd.next();
	if (arg != NULL)
	{
		power = atoi(arg);
		Serial.print("setting power: ");
		Serial.println(power);
		// not implemented
	}
	else
	{
		Serial.println("No arguments");
	}
}

uint8_t getMaxPWM(float volt, uint16_t pwm)
{
	uint16_t _maxWatt = volt * (volt / RTresist);
	_maxWatt = MAXWATT * 255 / _maxWatt;
	// Serial.println(_maxWatt);
	return constrain(_maxWatt, 0, 255);
}

void setBrightness()
{
	char *arg;
	uint16_t power;
	arg = sCmd.next();
	if (arg != NULL)
	{
		power = atoi(arg);
		Serial.print("setting brightness: ");
		Serial.println(power);
		analogWrite(BLpin, power);
	}
	else
	{
		Serial.println("No arguments");
	}
}

void setup(void)
{
	// change the prescaler for faster ADC
	// set up the ADC
	ADCSRA &= ~PS_128; // remove bits set by Arduino library
	ADCSRA |= PS_32;   // 32 prescaler

	SPI.setClockDivider(SPI_CLOCK_DIV2); // 4MHz

	Serial.begin(115200);
	sCmd.addCommand("P", setPower);
	sCmd.addCommand("B", setBrightness);

	// FastLED.addLeds<WS2812B, LED_PIN, GRB>(led, 1);
	// FastLED.setBrightness(BRIGHTNESS);
	// led[0] = CRGB::White;

	pinMode(BLpin, OUTPUT); // pin 7 geschaltet über Transistor
	// 												// pinMode(BLpinold, INPUT);   // pin 5 ist direkt mit BL verbunden und wird als Eingang definiert um nicht zu stören
	// digitalWrite(BLpin, LOW);

	pinMode(STANDBYin, INPUT_PULLUP);

	pinMode(PWMpin, OUTPUT);
	digitalWrite(PWMpin, LOW);
	setPwmFrequency(PWMpin, PWM_DIV);
	digitalWrite(PWMpin, LOW);
	analogWrite(BLpin, BRIGHTNESS);

	tft.initR(INITR_BLACKTAB);

	tft.setRotation(0); // 0 - Portrait, 1 - Lanscape
	tft.fillScreen(ST7735_BLACK);
	tft.setTextWrap(false);

	//Print station Logo
	tft.drawBitmap(2, 1, stationLOGO1, 124, 47, ST7735_GREY);
	tft.drawBitmap(3, 3, stationLOGO1, 124, 47, ST7735_YELLOW);
	tft.drawBitmap(3, 3, stationLOGO2, 124, 47, tft.Color565(254, 147, 52));
	tft.drawBitmap(3, 3, stationLOGO3, 124, 47, tft.Color565(255, 78, 0));

//BAcklight on
// digitalWrite(BLpin, HIGH);

#if defined(INTRO)
	delay(500);

	//Print Iron
	tft.drawBitmap(15, 50, iron, 100, 106, ST7735_GREY);
	tft.drawBitmap(17, 52, iron, 100, 106, ST7735_YELLOW);
	delay(500);

	tft.setTextSize(2);
	tft.setTextColor(ST7735_GREY);
	tft.setCursor(70, 130);
	tft.print(VERSION);

	tft.setTextSize(2);
	tft.setTextColor(ST7735_YELLOW);
	tft.setCursor(72, 132);
	tft.print(VERSION);

	tft.setTextSize(1);
	tft.setTextColor(ST7735_GREY);
	tft.setCursor(102, 0);
	tft.print("v");
	tft.print(VERSION);

	tft.setTextColor(ST7735_YELLOW);
	tft.setCursor(103, 1);
	tft.print("v");
	tft.print(VERSION);

	delay(2500);
#endif

	tft.fillRect(0, 47, 128, 125, ST7735_BLACK);
	tft.setTextColor(ST7735_WHITE);

	tft.setTextSize(1);
	tft.setCursor(1, 85);
	tft.print("ist");

	tft.setTextSize(2);
	tft.setCursor(117, 49);
	tft.print("o");

	tft.setTextSize(1);
	tft.setCursor(1, 128);
	tft.print("soll");

	tft.setTextSize(2);
	tft.setCursor(117, 94);
	tft.print("o");

	tft.setTextSize(1);
	tft.setCursor(1, 151); //60
	tft.print("pwm");
	// tft.setCursor(28, 144);
	// tft.print("0%");
	// tft.setCursor(104, 144);
	// // tft.print("100%");
	// tft.print();

	tft.setTextSize(2);
}

void loop()
{
	sCmd.readSerial();
	volt = getVolt();

	int actual_temperature = getTemperature();
	unsigned long currentMillis = millis();
	standby_act = !digitalRead(STANDBYin);
	int poti = analogRead(POTI);
	if (poti < POTIOFF)
		soll_temp = 0;
	else
		soll_temp = map(poti, POTIOFF, 1020, 150, MAX_POTI);

	if ((soll_temp - JITTER > disp_soll_temp) || (soll_temp + JITTER < disp_soll_temp))
	{
		disp_soll_temp = soll_temp;
	}

	if (standby_act != standby_act_old)
	{
		autoOffMillis = currentMillis;
	}

	if (standby_act && (soll_temp >= STANDBY_TEMP))
	{
		soll_temp_tmp = STANDBY_TEMP;
	}
	else
	{
		soll_temp_tmp = soll_temp;
	}

	if (currentMillis - autoOffMillis >= AUTO_OFF)
	{
		soll_temp_tmp = 0;
		autoOFF = true;
	}
	else
	{
		autoOFF = false;
	}

	int diff = (soll_temp_tmp + OVER_SHOT) - actual_temperature;
	pwm = diff * CNTRL_GAIN;

	int MAX_PWM;

	//Set max heating Power
	MAX_PWM = standby_act ? MAX_PWM_LOW : getMaxPWM(volt, pwm);

	//8 Bit Range
	pwm = pwm > MAX_PWM ? pwm = MAX_PWM : pwm < 0 ? pwm = 0 : pwm;

	//NOTfall sicherheit / Spitze nicht eingesteckt
	if (actual_temperature > 415)
	{
		pwm = 0;
		actual_temperature = 0;
	}

	analogWrite(PWMpin, pwm);
	watt = calcPower(volt, pwm);

	//digitalWrite(PWMpin, LOW);
	// calcPower(volt, pwm);

	if ((currentMillis - refreshMillis >= DISPLAY_REFRESH) ||
		((abs(soll_temp_tmp - actual_temperature) > 10) && !autoOFF && (currentMillis - refreshMillis >= DISPLAY_REFRESH / 8)) ||
		(standby_act != standby_act_old))
	{
		refreshMillis = currentMillis;
		writeHEATING(disp_soll_temp, actual_temperature);
	}

	writePWM(map(pwm, 0, MAX_PWM, 0, 100));

	//update LED
	// fastled.show();

	standby_act_old = standby_act;

	// delay(DELAY_MAIN_LOOP); //wait for some time
}

int getTemperature()
{
	analogWrite(PWMpin, 0); //switch off heater
	delay(DELAY_MEASURE);   //wait for some time (to get low pass filter in steady state)
	analogRead(TEMPin);		// read the input on analog pin 7:
	float adcValue;
	for (uint8_t i = 0; i < 8; i++)
		adcValue += analogRead(TEMPin); // read the input on analog pin 7:
	// adcValue = adcValue /4;
	// Serial.print("ADC Value ");
	// Serial.println(adcValue);
	analogWrite(PWMpin, pwm);												//switch heater back to last value
	return round(adcValue * (ADC_TO_TEMP_GAIN / 8.0) + ADC_TO_TEMP_OFFSET); //apply linear conversion to actual temperature
}

void writePWM(int pwmVAL)
{

	static int pwmVAL_OLD = 10;

	//TFT Anzeige

	// pwmVAL = map(pwmVAL, 0, 254, 0, 100);
	tft.setTextSize(2);
	if (autoOFF_old != autoOFF)
	{
		if (autoOFF)
		{
			tft.fillRect(0, 144, 128, 16, 0);
			tft.setCursor(2, 55);
			tft.setTextColor(ST7735_BLACK);
			tft.print("SB");
			tft.setCursor(0, 144);
			tft.setTextColor(ST7735_CYAN);
			tft.print("10min. OFF");
		}
		else
		{
			tft.setCursor(0, 144);
			tft.setTextColor(ST7735_BLACK);
			tft.print("10min. OFF");
			tft.setTextSize(1);
			tft.setTextColor(ST7735_WHITE);
			tft.setCursor(1, 151); //60
			tft.print("pwm");
			// tft.setCursor(28, 144);
			// tft.print("0%");
			// tft.setCursor(104, 144);
			// tft.print("100%");
			if (pwmVAL)
			{
				tft.fillRect(28, 153, pwmVAL, 12, ST7735_YELLOW);
				tft.fillRect(28 + pwmVAL, 153, 100 - pwmVAL, 12, ST7735_BLACK);
			}
			else
			{
				tft.fillRect(28, 153, 1, 12, ST7735_WHITE);
				tft.fillRect(29, 153, 99, 12, ST7735_BLACK);
			}
		}
	}
	else if ((pwmVAL_OLD != pwmVAL) && !autoOFF)
	{
		if (pwmVAL)
		{
			uint8_t _pwm = pwmVAL * 2.55;
			tft.fillRect(28, 153, pwmVAL, 12, tft.Color565(_pwm, 255 - _pwm, 0));
			if (pwmVAL != 100)
				tft.fillRect(28 + pwmVAL, 153, 100 - pwmVAL, 12, ST7735_BLACK);
		}
		else
		{
			tft.fillRect(28, 153, 1, 12, ST7735_WHITE);
			tft.fillRect(29, 153, 99, 12, ST7735_BLACK);
		}

		if (millis() - lastVupd > INTVUPD)
		{
			lastVupd = millis();

			tft.fillRect(28, 144, 30, 8, ST7735_BLACK);
			tft.setTextSize(1);
			tft.setCursor(28, 144);

			if (volt < 10.0)
			{
				tft.setTextColor(ST7735_BLACK);
				tft.print(' ');
			}
			tft.setTextColor(ST7735_WHITE);
			tft.print(volt);
			tft.print('V');

			tft.fillRect(80, 144, 30, 8, ST7735_BLACK);

			if (watt >= MAXWATT - 1)
				tft.setTextColor(ST7735_RED);
			tft.setCursor(80, 144);
			if (watt < 10)
				tft.print(' ');
			tft.print(watt);
			tft.print('W');
		}
	}
	autoOFF_old = autoOFF;
}

void writeHEATING(int tempSOLL, int tempVAL)
{

	static int tempSOLL_OLD = 10;
	static int tempVAL_OLD = 10;

	tft.setTextSize(5);
	if (tempVAL_OLD != tempVAL)
	{
		tft.setCursor(30, 57);
		tft.setTextColor(ST7735_BLACK);
		if ((tempVAL_OLD / 100) != (tempVAL / 100))
		{
			tft.print(tempVAL_OLD / 100);
		}
		else
		{
			tft.print(" ");
		}
		if (((tempVAL_OLD / 10) % 10) != ((tempVAL / 10) % 10))
		{
			tft.print((tempVAL_OLD / 10) % 10);
		}
		else
		{
			tft.print(" ");
		}
		if ((tempVAL_OLD % 10) != (tempVAL % 10))
		{
			tft.print(tempVAL_OLD % 10);
		}
		tft.setCursor(30, 57);
		tft.setTextColor(ST7735_WHITE);
		if (tempVAL < 100)
		{
			tft.print(" ");
		}
		if (tempVAL < 10)
		{
			tft.print(" ");
		}
		if (standby_act && !autoOFF)
		{
			tft.setTextColor(ST7735_BLUE);
			// led[0].r = 0;
			// led[0].g = 0;
			// led[0].b = 255;
		}
		else if (autoOFF)
		{
			tft.setTextColor(ST7735_CYAN);
			// led[0].r = 0;
			// led[0].g = 0;
			// led[0].b = 0;
		}
		else
		{
			int tempDIV = tempSOLL - tempVAL;
			tempDIV = tempDIV > 255 ? tempDIV = 255 : tempDIV < 0 ? tempDIV = 0 : tempDIV;
			int tempR = (tempDIV * (255 / DISPLAY_FADE_DIFF)) - (DISPLAY_FADE_DIFF_TEMP - DISPLAY_FADE_DIFF);
			tempR = tempDIV >= DISPLAY_FADE_DIFF_TEMP ? tempR = 255 : tempR > 255 ? tempR = 255 : tempR < 0 ? tempR = 0 : tempR;
			int tempG = 255 + (DISPLAY_FADE_DIFF_TEMP * (255 / DISPLAY_FADE_DIFF)) - (tempDIV * (255 / DISPLAY_FADE_DIFF));
			tempG = tempDIV <= DISPLAY_FADE_DIFF_TEMP ? tempG = 255 : tempG < 0 ? tempG = 0 : tempG > 255 ? tempG = 255 : tempG;
			tft.setTextColor(tft.Color565((uint8_t)tempR, (uint8_t)tempG, 0));
			// led[0].r = tempR;
			// led[0].g = tempG;
			// led[0].b = 0;
		}
		tft.print(tempVAL);
		tft.setTextSize(1);
		tft.setCursor(1, 85);
		tft.print("ist");
		tft.setTextSize(2);
		tft.setCursor(117, 49);
		tft.print("o");
		tempVAL_OLD = tempVAL;
		tft.setCursor(2, 55);
		if (standby_act && !autoOFF)
		{
			tft.setTextColor(ST7735_BLUE);
		}
		else
		{
			tft.setTextColor(ST7735_BLACK);
		}
		tft.print("SB");
	}

	tft.setTextSize(4);
	if (tempSOLL_OLD != tempSOLL)
	{
		tft.setCursor(40, 106);
		tft.setTextColor(ST7735_BLACK);
		if ((tempSOLL_OLD / 100) != (tempSOLL / 100))
		{
			tft.print(tempSOLL_OLD / 100);
		}
		else
		{
			tft.print(" ");
		}
		if (((tempSOLL_OLD / 10) % 10) != ((tempSOLL / 10) % 10))
		{
			tft.print((tempSOLL_OLD / 10) % 10);
		}
		else
		{
			tft.print(" ");
		}
		if ((tempSOLL_OLD % 10) != (tempSOLL % 10))
		{
			tft.print(tempSOLL_OLD % 10);
		}

		//Neuen Wert in Weiß schreiben
		tft.setCursor(40, 106);
		tft.setTextColor(ST7735_WHITE);
		if (tempSOLL < 100)
		{
			tft.print(" ");
		}
		if (tempSOLL < 10)
		{
			tft.print(" ");
		}
		tft.print(tempSOLL);
		tempSOLL_OLD = tempSOLL;
	}
}

void setPwmFrequency(int pin, int divisor)
{
	byte mode;
	if (pin == 5 || pin == 6 || pin == 9 || pin == 10)
	{
		switch (divisor)
		{
		case 1:
			mode = 0x01;
			break;
		case 8:
			mode = 0x02;
			break;
		case 64:
			mode = 0x03;
			break;
		case 256:
			mode = 0x04;
			break;
		case 1024:
			mode = 0x05;
			break;
		default:
			return;
		}

		if (pin == 5 || pin == 6)
		{
			TCCR0B = TCCR0B & 0b11111000 | mode;
		}
		else
		{
			TCCR1B = TCCR1B & 0b11111000 | mode;
		}
	}
	else if (pin == 3 || pin == 11)
	{
		switch (divisor)
		{
		case 1:
			mode = 0x01;
			break;
		case 8:
			mode = 0x02;
			break;
		case 32:
			mode = 0x03;
			break;
		case 64:
			mode = 0x04;
			break;
		case 128:
			mode = 0x05;
			break;
		case 256:
			mode = 0x06;
			break;
		case 1024:
			mode = 0x07;
			break;
		default:
			return;
		}

		TCCR2B = TCCR2B & 0b11111000 | mode;
	}
}

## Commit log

2016-04-24 Textposition angepasst.
    [solderstation_gehäuse.dxf]
2016-05-22 backlight pin, Anzeige beruhigt und Farbübergang
    pin 5 ist direkt an BL angeschlossen
    pin 7 auch aber verstärkt über einen Transistor
    pin 5 wurde als Eingang eingestellt und statt dessen wird pin 7 für die
    Hintergrundbeleuchtung verwendet
    Die Farbübergänge waren nicht einstellbar und stellenweise zu dunkel.
    Sie sind jetzt immer gleich hell und die Temperaturabstände sind
    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
2016-05-28 PWM-Balken und AutoOff nach 10min
2016-06-26 3d bottom mod + handle
    [hand.scad, lotstationv2.2.scad, lotstationv2.2.stl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]
2017-06-27 PlatformIO init
    [SolderStation.kicad_pcb, SolderStation.sch]
2017-06-28 adc calibration
